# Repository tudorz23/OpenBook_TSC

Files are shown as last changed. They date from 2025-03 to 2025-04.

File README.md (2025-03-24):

*Designed by Marius-Tudor Zaharia, 333CA, March 2025*

# OpenBook

---

## What is OpenBook?
* OpenBook is an implementation of a performant, yet accessible e-book reader,
following an open-source philosophy, with Wi-Fi connectivity.
* It focuses on minimalism and offers a distraction-free body, with three
physical buttons for efficient navigation.
* It also promotes environmental awareness, encompassing temperature, humidity,
air pressure and air quality sensors.

---

## Block diagram
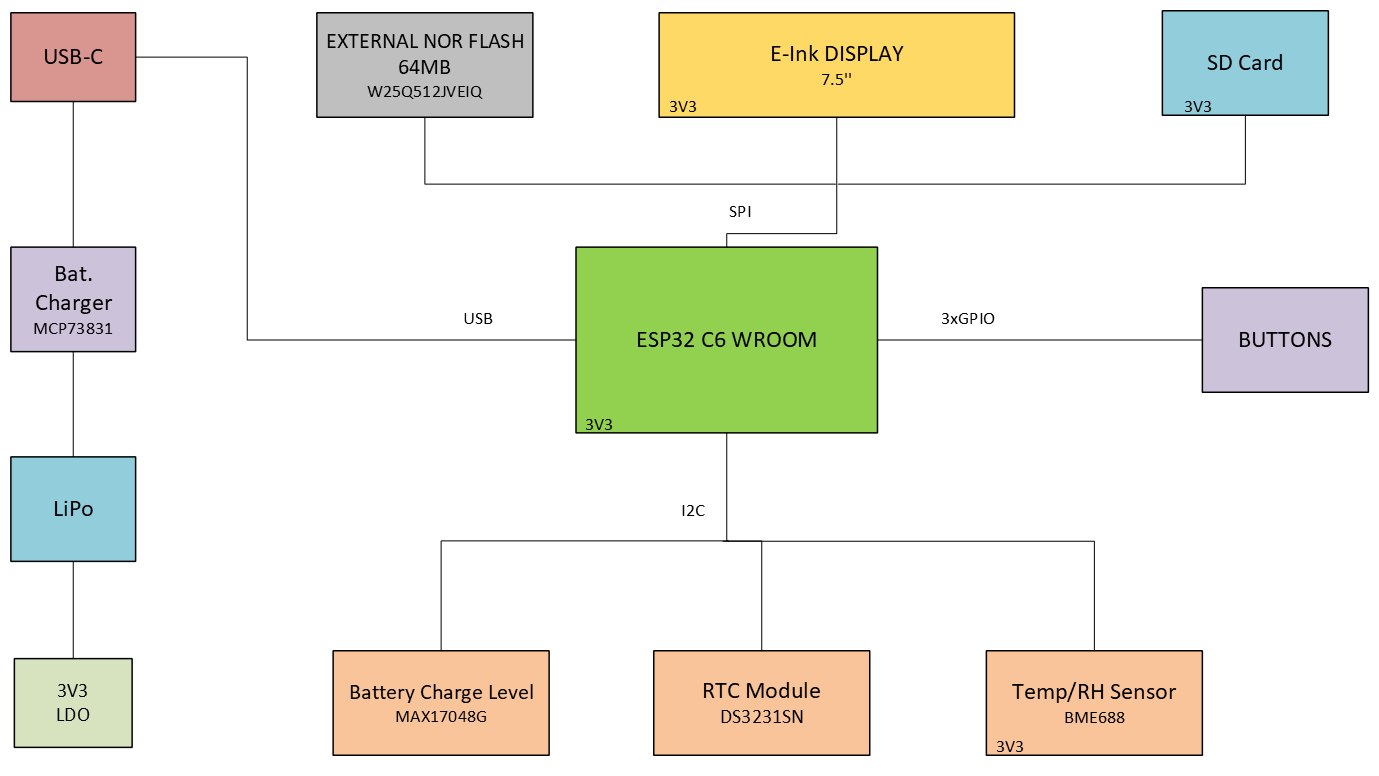
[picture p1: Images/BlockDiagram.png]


---

## Hardware description
### PCB
* The design of the PCB is centered around an **ESP32 C6 WROOM** microcontroller,
equipped with a 32-bit RISC-V single-core processor, up to 160MHz.
    * It offers 320 KB ROM, 512KB HP SRAM, 16KB LP SRAM.
    * It comes with Wi-Fi 6 and Bluetooth LE connectivity.
    * Supports GPIO, SPI, UART, I2C, LED PWM.

* The **ESP32** supports *5 power modes*, each with a different power consumption index:
    * *Active* - between 160 and 260mA
    * *Modem Sleep* - between 3 and 20mA
    * *Light Sleep* - 0.8mA
    * *Deep Sleep* - 10uA
    * *Hibernation* - 2.5uA

* **Three Buttons** are connected to 3 GPIO pins of the ESP32, allowing the user
                    to control the device:
    * *Reset* to **pin 3 - Enable**
    * *Boot* to **pin 15 - GPIO 9**
    * *Change* to **pin 23 - GPIO 15**

* **SD Card** socket, which communicates by SPI protocol:
    * *pin 2 - CD/DAT3* to **pin 4 - GPIO 4**
    * *pin 3 - CMD* to **pin 7** (MOSI, i.e. Serial Data Out, for SPI)
    * *pin 7 - DAT0* to **pin 27** (MISO, i.e. Serial Data In, for SPI)
    * *pin 5* to **pin 6 - clock**

* **E-Paper Display Header**, interfacing the external E-Ink Display, also by SPI.

* **External NOR Flash Memory 64MB**, by SPI too:
    * *pin 1 - CS* to **pin 12 - GPIO 11**
    * *pin 2* to **MOSI** (for SPI)
    * *pin 5* to **MISO** (for SPI)
    * *pin 6* to **pin 6 - clock**

* **RTC Module** - Real Time Clock, using I2C protocol:
    * *pin 4 - Reset* to **pin 16 - GPIO 18**
    * *pin 16 - SCL* to **pin 20 - GPIO 22** (for I2C)
    * *pin 15 - SDA* to **pin 19 - GPIO 21** (for I2C)
    * *pin 1* to **pin 9 - GPIO 1** (for 32KHz)
    * *pin 3 - SQW/INT* to **pin 8 - GPIO 0**
    * Has a battery backup input for continuous timekeeping.

* **BME688** - Digital low power pressure, temperature, humidity and gas sensor,
               also interfaced through I2C:
    * *pin 4 - SCK* to **pin 20 - GPIO 22** (SCL for I2C)
    * *pin 15 - SDI* to **pin 19 - GPIO 21** (SDA for I2C)
    * *pins 2, 6, 8* to **pin 17 - GPIO 19** (for I2C PW)
    * Power consumption is 3.7uA at 1Hz humidity, pressure and temperature scan
        and 0.15uA in sleep mode.

* **USB-C connector** - for fast, efficient charging.

* **Li-Po Battery Charging Controller** - MCP73831

* **LDO Voltage Regulator**

* **Battery Charge Level** - *MAX17048G+T10*, communicates by I2C interface:
    * *pin 7 - SCL* to **pin 20 - GPIO 22**
    * *pin 8 - SDA* to **pin 19 - GPIO 21**
    * Power consumption is 23uA in Active state and 3uA in Hibernate.

### External
* **7.5" E-Paper Display**
* **2500mAh Battery - LP584174**

---

## Bill Of Materials
| Component | Price (EUR) | Count | Provider | Datasheet |
| :--- | :--- | :---  | :--- | :--- |
| ESP32 C6| 2.99 | 1 | https://eu.mouser.com/ProductDetail/Espressif-Systems/ESP32-C6-WROOM-1U-N8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 | https://eu.mouser.com/datasheet/2/891/Espressif_Systems_7_11_2023_esp32_c6_wroom_1_wroom-3236277.pdf |
| USB-C connector| 0.39 | 1 | https://eu.mouser.com/ProductDetail/Same-Sky/UJC-H-G-SMT-2-P6-TR?qs=IKkN%2F947nfApFV8T6rOqww%3D%3D |https://eu.mouser.com/datasheet/2/1628/ujc_h_g_smt_2_p6_tr-3511211.pdf |
| USBLC6-2SC6Y | 0.44 | 1 | https://eu.mouser.com/ProductDetail/STMicroelectronics/USBLC6-2SC6Y?qs=gNDSiZmRJS%2FOgDexvXkdow%3D%3D | https://eu.mouser.com/datasheet/2/389/usblc6_2sc6y-1852505.pdf |
| PFMF.050.1 | 0.28 | 1 | https://eu.mouser.com/ProductDetail/Schurter/PFMF.050.2?qs=1auRipcfynCums5v1iucSA%3D%3D | https://eu.mouser.com/datasheet/2/358/typ_PFMF-1275918.pdf |
| DMG2305UX-7 | 0.19 | 2 | https://eu.mouser.com/ProductDetail/Diodes-Incorporated/DMG2305UX-7?qs=L1DZKBg7t5F%2FNBHrjfxC%252Bg%3D%3D | https://www.diodes.com/assets/Datasheets/DMG2305UX.pdf |
| SD0805S020S1R0 | 0.3 | 2 | https://eu.mouser.com/ProductDetail/KYOCERA-AVX/SD0805S020S1R0?qs=jCA%252BPfw4LHbpkAoSnwrdjw%3D%3D | https://eu.mouser.com/datasheet/2/40/schottky-3165252.pdf |
| XC6220A331MR-G | 1.46 | 1 | https://eu.mouser.com/ProductDetail/Torex-Semiconductor/XC6220A331MR-G?qs=AsjdqWjXhJ8ZSWznL1J0gg%3D%3D | https://eu.mouser.com/datasheet/2/760/xc6220-3371556.pdf |
| TANT Capacitor | 0.68 | 1 | https://eu.mouser.com/ProductDetail/Vishay-Sprague/293D107X9010D2TE3?qs=8dfOI6wKXonVqFgS8%252BQ%2FMA%3D%3D | https://www.vishay.com/docs/40002/293d.pdf |
| 112A-TAAR-R03 | 1.1 | 1 | https://store.comet.srl.ro/Catalogue/Product/43497/ | https://store.comet.bg/download-file.php?id=27596 |
| 68uH inductance | 0.9 | 1 | https://eu.mouser.com/ProductDetail/Vishay-Dale/IFDC5050JZER680M?qs=iLKYxzqNS745SePZd8tBoA%3D%3D | https://www.vishay.com/docs/34635/ifdc5050jz.pdf |
| MBR0530 | 0.14 | 3 | https://eu.mouser.com/ProductDetail/Micro-Commercial-Components-MCC/MBR0530-TP?qs=KFo7JewZbUECRHkxGanrdg%3D%3D | https://eu.mouser.com/datasheet/2/258/MBR0520_MBR0580_SOD123_-2492194.pdf |
| SI1308EDL-T1-GE3 | 0.42 | 2 | https://eu.mouser.com/ProductDetail/Vishay-Semiconductors/SI1308EDL-T1-GE3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 | https://www.vishay.com/docs/63399/si1308edl.pdf |
| Capacitor 0.1uF | 0.3 | 1 | https://eu.mouser.com/ProductDetail/KYOCERA-AVX/KGF21BR71H104KT?qs=Jm2GQyTW%2FbjYyKCvVWAEOw%3D%3D | https://eu.mouser.com/datasheet/2/40/KGF-3223650.pdf |
| Capacitor 1uF | 0.13 | 10 | https://eu.mouser.com/ProductDetail/TAIYO-YUDEN/MAASL105CC7105MFCA01?qs=HFfMDpzxxd1Fn%2FInbJA7vw%3D%3D | https://eu.mouser.com/datasheet/2/396/TAIYO_YUDEN_04_27_2024_c_mlcc_A_e1-3451516.pdf |
| Capacitor 4.7uF | 0.23 | 5 | https://eu.mouser.com/ProductDetail/KYOCERA-AVX/CM05X5R475M16AH?qs=doiCPypUmgFT1xquZKhWtQ%3D%3D | https://eu.mouser.com/datasheet/2/40/Kyocera_AVX_Components_CM025_CM05_CM105_CM21_E217K-2932876.pdf |
| Capacitor 10 uF | 0.47 | 1 | https://eu.mouser.com/ProductDetail/TDK/CGA3EDX7T1A106M080AU?qs=ZcfC38r4PovL%2FBNBUzzBFw%3D%3D | https://product.tdk.com/system/files/dam/doc/product/capacitor/ceramic/mlcc/catalog/mlcc_automotive_general_en.pdf |
| Capacitor 100nF | 0.3 | 8 | https://eu.mouser.com/ProductDetail/KYOCERA-AVX/KAM21BR71H104JT?qs=Jm2GQyTW%2Fbic6Zk4McEt6w%3D%3D | https://eu.mouser.com/datasheet/2/40/AutoMLCCKAM-3216307.pdf |
| Resistor 0.47 | 0.3 | 1 | https://eu.mouser.com/ProductDetail/SEI-Stackpole/RNCL1210FT50L0?qs=17ckDYBRdelVLOJ%252BDFjlUw%3D%3D | https://eu.mouser.com/datasheet/2/385/sei_rncl-3223524.pdf |
| Resistor 2.2 | 0.13 | 1 | https://eu.mouser.com/ProductDetail/YAGEO/RT1206FRE072R2L?qs=XhSZopxZ3H6S0nYZD83pAA%3D%3D | https://eu.mouser.com/datasheet/2/447/PYu_RT_1_to_0_01_RoHS_L_15-3461507.pdf |
| Resistor 15 | 0.25 | 1 | https://eu.mouser.com/ProductDetail/Panasonic/ERA-6AHD150V?qs=MNPzkKEzRtQip8ZeekU%252BRw%3D%3D | https://industrial.panasonic.com/cdbs/www-data/pdf/RDM0000/AOA0000C307.pdf |
Resistor 200 | 0.33 | 1 | https://eu.mouser.com/ProductDetail/TE-Connectivity-Holsworthy/RP73C2B200RFTDF?qs=n4i9pByFsMR0dWGpf721CA%3D%3D | https://eu.mouser.com/datasheet/2/418/10/ENG_DS_1773272_M1-1588495.pdf |
| Resistor 2k | 0.16 | 1 | https://eu.mouser.com/ProductDetail/Panasonic/ERA-3AED202V?qs=yocZuyCaXdM2cBmjcGkIyA%3D%3D | https://industrial.panasonic.com/cdbs/www-data/pdf/RDM0000/AOA0000C307.pdf |
| Resistor 5k1 | 0.15 | 2 | https://eu.mouser.com/ProductDetail/Vishay-Beyschlag/MCS04020C5101FE000?qs=wTZ%2FFzl837YsKPLPRIXUbg%3D%3D | https://www.vishay.com/docs/28705/mcx0x0xpro.pdf |
| Resistor 10k | 0.32 | 16 | https://eu.mouser.com/ProductDetail/SEI-Stackpole/RNWA0612BTE10K0?qs=IKkN%2F947nfD62pDKWE9ZTQ%3D%3D | https://eu.mouser.com/datasheet/2/385/SEI_RNWA-3473840.pdf |
| Resistor 100K | 0.1 | 1 | https://eu.mouser.com/ProductDetail/Panasonic/ERA-3AED104V?qs=MNPzkKEzRtQIWcmUWL4kjg%3D%3D | https://industrial.panasonic.com/cdbs/www-data/pdf/RDM0000/AOA0000C307.pdf |
| MCP73831 | 0.75 | 1 | https://eu.mouser.com/ProductDetail/Microchip-Technology/MCP73831-2ACI-MC?qs=hH%252BOa0VZEiBneYTVdpuVdg%3D%3D | https://eu.mouser.com/datasheet/2/268/MCP73831_Family_Data_Sheet_DS20001984H-3441711.pdf |
| FH34SRJ-24S-0.5SH(99) | 2.6 | 1 | https://eu.mouser.com/ProductDetail/Hirose-Connector/FH34SRJ-24S-0.5SH99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 | https://eu.mouser.com/datasheet/2/185/FH34SRJ_24S_0_5SH_99__CL0580_1255_6_99_2DDrawing_0-1615044.pdf |
| BME688 | 9.86 | 1 | https://eu.mouser.com/ProductDetail/Bosch-Sensortec/BME688?qs=IS%252B4QmGtzzqQoVDscqwx3A%3D%3D | https://eu.mouser.com/datasheet/2/783/bst_bme688_fl000-2307034.pdf |
| BD5229G-TR | 0.75 | 1 | https://eu.mouser.com/ProductDetail/ROHM-Semiconductor/BD5229G-TR?qs=4kLU8WoGk0vvnhrrYwdszw%3D%3D | https://fscdn.rohm.com/en/products/databook/datasheet/ic/power/voltage_detector/bd52xxg-e.pdf |
| MAX17048G+T10 | 4.28 | 1 | https://eu.mouser.com/ProductDetail/Analog-Devices-Maxim-Integrated/MAX17048G%2bT10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 | https://eu.mouser.com/datasheet/2/609/MAX17048_MAX17049-3469099.pdf |
| DS3231SN# | 14.91 | 1 | https://eu.mouser.com/ProductDetail/Analog-Devices-Maxim-Integrated/DS3231SN?qs=1eQvB6Dk1vhUlr8%2FOrV0Fw%3D%3D | https://eu.mouser.com/datasheet/2/609/DS3231-3421123.pdf |
| CPH3225A | 2.33 | 1 | https://eu.mouser.com/ProductDetail/Seiko-Semiconductors/CPH3225A?qs=3etwrb1wR%252BhUOph6lAO7eg%3D%3D | https://eu.mouser.com/datasheet/2/360/Seiko_Instruments_MicroBattery_E_20230330_2024Jan_-3561061.pdf |
| Qwiic | 3.75 | 1 | https://eu.mouser.com/ProductDetail/Adafruit/4208?qs=PzGy0jfpSMtbScLbr0L5dw%3D%3D | https://learn.adafruit.com/introducing-adafruit-stemma-qt/technical-specs |
| PGB1010603MR | 0.4 | 6 | https://eu.mouser.com/ProductDetail/Littelfuse/PGB1010603MR?qs=gu7KAQ731URLg4GSnNNN7Q%3D%3D | https://www.littelfuse.com/assetdocs/pulseguard-esd-suppressors-pgb1-datasheet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 |
| W25Q512JVEIQ | 5.84 | 1 | https://eu.mouser.com/ProductDetail/Winbond/W25Q512JVEIQ?qs=l7cgNqFNU1jw6svr3at6tA%3D%3D | https://eu.mouser.com/datasheet/2/949/Winbond_W25Q512JV_Datasheet-3240039.pdf |
| LP584174 Battery| 6.4 | 1 | https://www.tme.eu/en/details/accu-lp584174_cl/rechargeable-batteries/cellevia-batteries/l584174/ | https://www.tme.eu/Document/e0683d8c34e6d878124489f71bffb6ee/cel0014.pdf |
| E-Paper Display | 48 | 1 | https://eu.mouser.com/ProductDetail/Microtips-Technology/MT-DEPG0750BNU590F1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 | https://eu.mouser.com/datasheet/2/271/MT_DEPG0750BNU590F1_V2_7-1894282.pdf |

* **Total Cost** : 124.66 EUR

---

## Implementation steps
* Firstly, I drew the schematic, with all the components.
* I drew the shape of the PCB, then I placed the components, all of them on the
top plane, taking into account the position they will occupy in the external case.
* I drew the ground plane for both top and bottom, then I used the autorouter to
shape the routes. I manually routed those that were left as airwires and corrected
the ones that were not so greatly done.
* I set the power routes to a width of 0.3mm and solved all the issues from the
DRC check, such as the angles of the routes.
* After fine-tuning the silkscreen, I pushed the PCB to 3D and placed it into
the case, alongside the battery and the display.

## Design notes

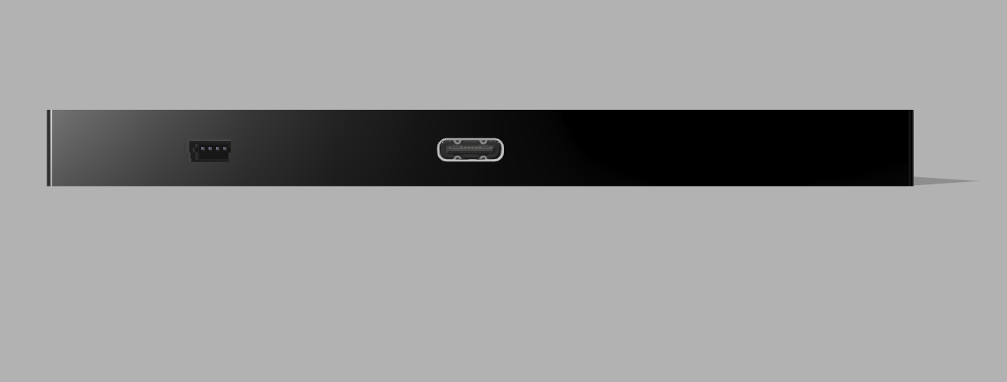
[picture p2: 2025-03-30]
Images/Device_bottom.png

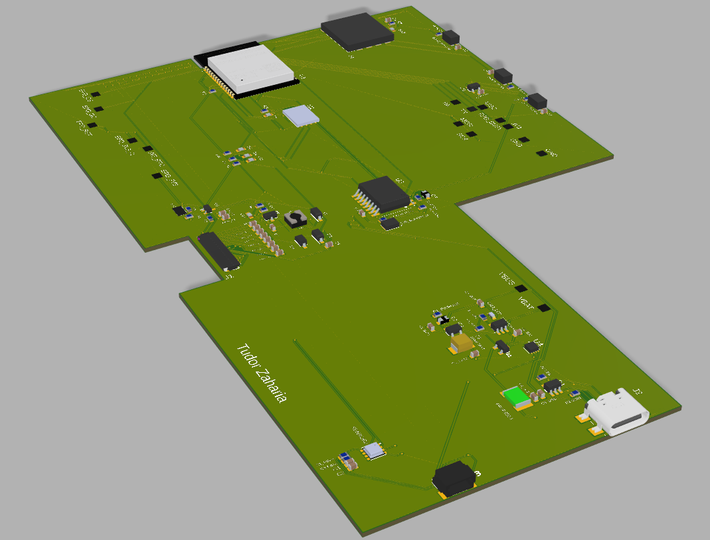
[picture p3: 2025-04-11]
Images/PCB_3D_side.png

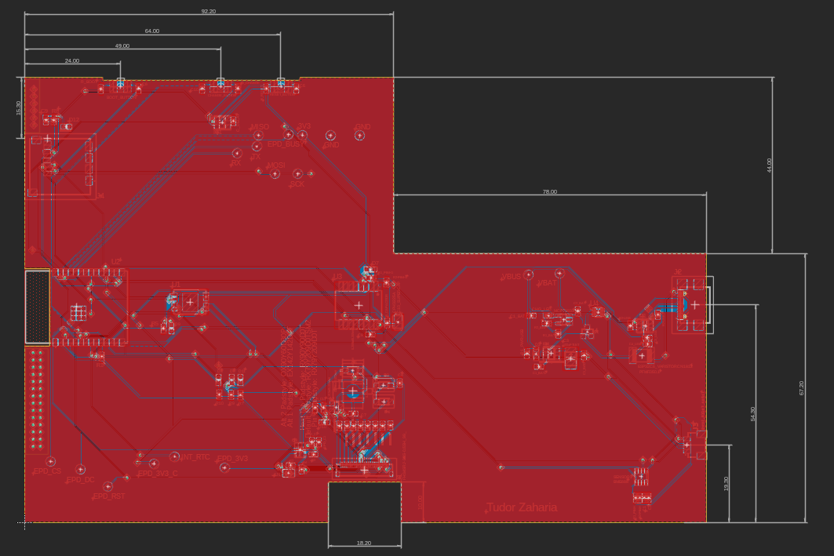
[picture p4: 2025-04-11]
Images/PCB_2D.png

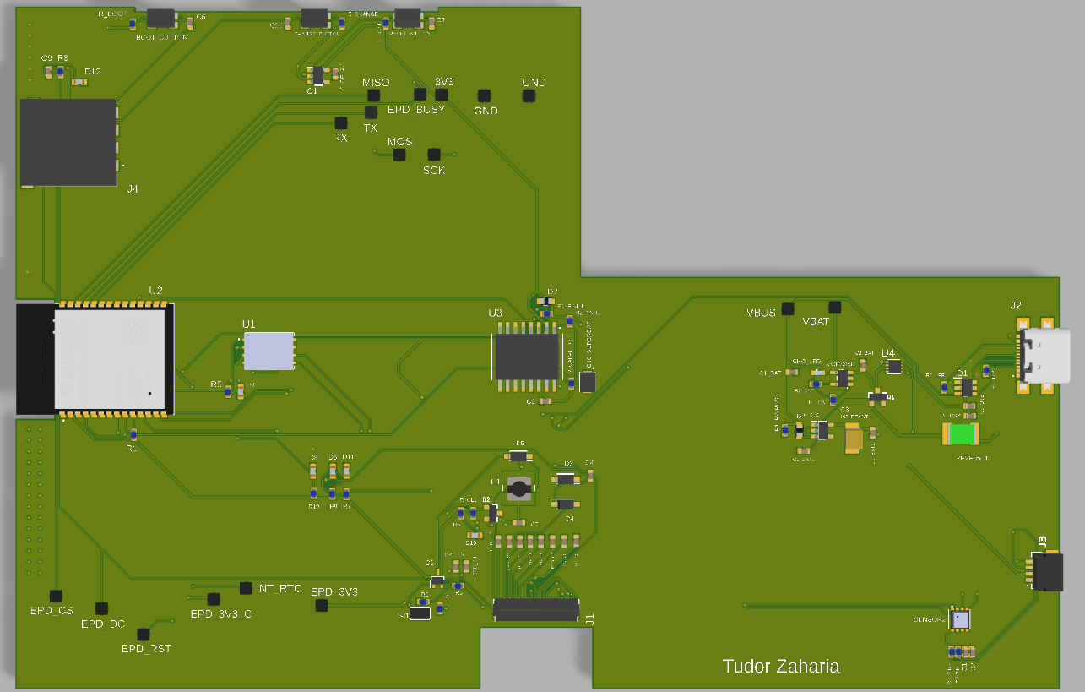
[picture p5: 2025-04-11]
Images/pcb_3d_top.png

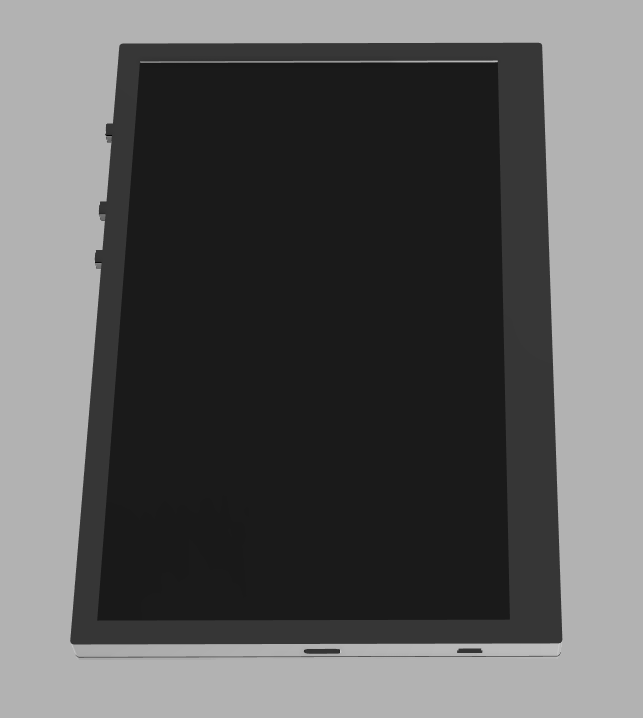
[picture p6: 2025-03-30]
Images/Device_display.png

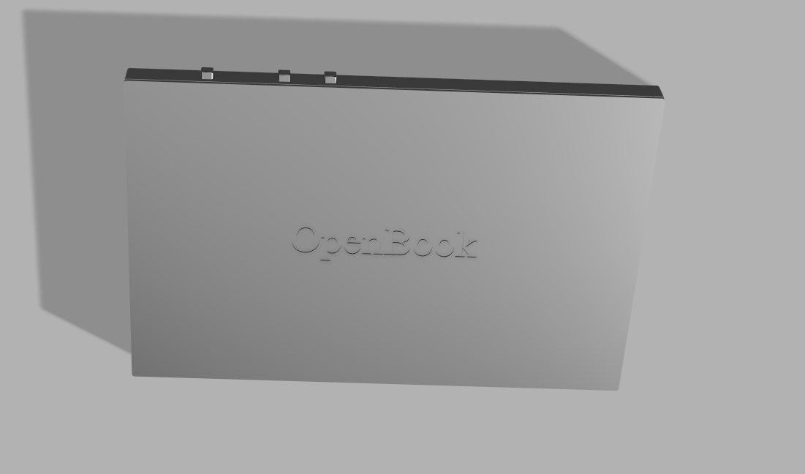
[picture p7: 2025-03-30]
Images/Device_back.png

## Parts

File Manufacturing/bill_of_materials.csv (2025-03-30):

Qty | Value | Device | Package | Parts | Description | ARROW_PART_NUMBER | ARROW_PRICE-STOCK | AVAILABILITY | CENTROID_NOT_SPECIFIED | CHECK_PRICES | COPYRIGHT | DATASHEET | DESCRIPTION | DIGIKEY_DESCRIPTION | DIGIKEY_PART_NUMBER | HEIGHT | LEAD_FREE | MANUFACTURER_NAME | MANUFACTURER_PART_NUMBER | MF | MFR_NAME | MOUSER_PART_NUMBER | MOUSER_PRICE-STOCK | MOUSER_TESTING_PART_NUMBER | MOUSER_TESTING_PRICE-STOCK | MP | MPN | PACKAGE | POPULARITY | PREFIX | PRICE | PROD_ID | PURCHASE-URL | ROHS | SNAPEDA_LINK | SPICEMODEL | SPICEPREFIX | TEMPERATURE_RANGE_HIGH | TEMPERATURE_RANGE_LOW | TP_SIGNAL_NAME | VALUE
1 |  | ADAFRUIT_LEDCHIP-LED0603 | ADAFRUIT_CHIP-LED0603 | CHG_LED | LED
1 |  | SJ | SJ | SJ1 | SMD solder JUMPER |  |  |  |  |  |  |  |  |  |  |  |  |  |  |  |  |  |  |  |  |  |  |  | 3
1 | 0.1uF/50V | EAGLE-LTSPICE_CC0402 | EAGLE-LTSPICE_C0402 | EPD_C5 | CAPACITOR, European symbol |  |  |  |  |  |  |  |  |  |  |  |  |  |  |  |  |  |  |  |  |  |  |  |  |  |  |  |  |  |  | NONE | C
1 | 0.47 | ESP32_WROVER_EAGLE-LTSPICE_RR0402 | ESP32_WROVER_EAGLE-LTSPICE_R0402 | R3 | RESISTOR, European symbol |  |  |  |  |  |  |  |  |  |  |  |  |  |  |  |  |  |  |  |  |  |  |  |  |  |  |  |  |  |  | NONE | R
1 | 100K | ESP32_WROVER_EAGLE-LTSPICE_RR0402 | ESP32_WROVER_EAGLE-LTSPICE_R0402 | R1_PWRUSB | RESISTOR, European symbol |  |  |  |  |  |  |  |  |  |  |  |  |  |  |  |  |  |  |  |  |  |  |  |  |  |  |  |  |  |  | NONE | R
8 | 100nF | EAGLE-LTSPICE_CC0402 | EAGLE-LTSPICE_C0402 | C1, C2, C4_USB, C6, C8, C9, C10, C_DELAY | CAPACITOR, European symbol |  |  |  |  |  |  |  |  |  |  |  |  |  |  |  |  |  |  |  |  |  |  |  |  |  |  |  |  |  |  | NONE | C
1 | 100uF TANT | RCL_CPOL-EUCT3528 | RCL_CT3528 | C3 | POLARIZED CAPACITOR, European symbol |  |  |  |  |  |  |  |  |  |  |  |  |  |  |  |  |  |  |  |  |  |  |  | 0 |  |  |  |  |  |  |  | C
16 | 10K | ESP32_WROVER_EAGLE-LTSPICE_RR0402 | ESP32_WROVER_EAGLE-LTSPICE_R0402 | R1, R1_PINH, R1_PINH1, R2-PINH, R2-PINH1, R4, R5, R6, R7, R8, R9, R10, R_BOOT, R_CHANGE, R_CL1, R_RESET | RESISTOR, European symbol |  |  |  |  |  |  |  |  |  |  |  |  |  |  |  |  |  |  |  |  |  |  |  |  |  |  |  |  |  |  | NONE | R
1 | 10uF | EAGLE-LTSPICE_CC0402 | EAGLE-LTSPICE_C0402 | C7 | CAPACITOR, European symbol |  |  |  |  |  |  |  |  |  |  |  |  |  |  |  |  |  |  |  |  |  |  |  |  |  |  |  |  |  |  | NONE | C
1 | 112A-TAAR-R03_ATTEND | 112A-TAAR-R03_ATTEND | 112ATAARR03ATTEND | J4 | Micro SD Card Socket, Push-Push Type, Top Mount, SMT, H=1.83mm, 10u |  |  |  |  |  |  |  | Micro SD Card Socket | Push-Push Type | Top Mount | SMT | H=1.83mm | 10u |  |  | 1.9mm |  | ATTEND | 112A-TAAR-R03 ATTEND
1 | 15 | ESP32_WROVER_EAGLE-LTSPICE_RR0402 | ESP32_WROVER_EAGLE-LTSPICE_R0402 | R_CAPACITOR | RESISTOR, European symbol |  |  |  |  |  |  |  |  |  |  |  |  |  |  |  |  |  |  |  |  |  |  |  |  |  |  |  |  |  |  | NONE | R
1 | 1uF | EAGLE-LTSPICE_CC0402 | EAGLE-LTSPICE_C0402 | C5 | CAPACITOR, European symbol |  |  |  |  |  |  |  |  |  |  |  |  |  |  |  |  |  |  |  |  |  |  |  |  |  |  |  |  |  |  | NONE | C
9 | 1uF/50V | EAGLE-LTSPICE_CC0402 | EAGLE-LTSPICE_C0402 | EPD_C1, EPD_C2, EPD_C6, EPD_C7, EPD_C8, EPD_C9, EPD_C10, EPD_C11, EPD_C12 | CAPACITOR, European symbol |  |  |  |  |  |  |  |  |  |  |  |  |  |  |  |  |  |  |  |  |  |  |  |  |  |  |  |  |  |  | NONE | C
1 | 2.2 | ESP32_WROVER_EAGLE-LTSPICE_RR0402 | ESP32_WROVER_EAGLE-LTSPICE_R0402 | R2 | RESISTOR, European symbol |  |  |  |  |  |  |  |  |  |  |  |  |  |  |  |  |  |  |  |  |  |  |  |  |  |  |  |  |  |  | NONE | R
1 | 200 | ESP32_WROVER_EAGLE-LTSPICE_RR0402 | ESP32_WROVER_EAGLE-LTSPICE_R0402 | R1_BAT | RESISTOR, European symbol |  |  |  |  |  |  |  |  |  |  |  |  |  |  |  |  |  |  |  |  |  |  |  |  |  |  |  |  |  |  | NONE | R
2 | 20V/4.2A/52mO/1.4W | ESP32_WROVER_SPARKFUN-DISCRETESEMI_MOSFET_PCH-DMG2305UX-7 | ESP32_WROVER_SPARKFUN-DISCRETESEMI_SOT23-3 | Q1, Q2 | P-channel MOSFETs |  |  |  |  |  |  |  |  |  |  |  |  |  |  |  |  |  |  |  |  |  |  |  |  |  |  | TRAN-14388 |  |  |  |  |  |  |  |  | 20V/4.2A/52mO/1.4W
1 | 2K | ESP32_WROVER_EAGLE-LTSPICE_RR0402 | ESP32_WROVER_EAGLE-LTSPICE_R0402 | R2_BAT | RESISTOR, European symbol |  |  |  |  |  |  |  |  |  |  |  |  |  |  |  |  |  |  |  |  |  |  |  |  |  |  |  |  |  |  | NONE | R
1 | 3V3 | TPTP20R | TP20R | TP16 | Test pad |  |  |  |  |  |  |  |  |  |  |  |  |  |  |  |  |  |  |  |  |  |  |  | 2
5 | 4.7uF | EAGLE-LTSPICE_CC0402 | EAGLE-LTSPICE_C0402 | C1_BAT, C1_BAT1, C1_BAT2, C2_BAT, C5_USB | CAPACITOR, European symbol |  |  |  |  |  |  |  |  |  |  |  |  |  |  |  |  |  |  |  |  |  |  |  |  |  |  |  |  |  |  | NONE | C
1 | 4.7uF/25V | EAGLE-LTSPICE_CC0402 | EAGLE-LTSPICE_C0402 | C4 | CAPACITOR, European symbol |  |  |  |  |  |  |  |  |  |  |  |  |  |  |  |  |  |  |  |  |  |  |  |  |  |  |  |  |  |  | NONE | C
2 | 5k1 | ESP32_WROVER_EAGLE-LTSPICE_RR0402 | ESP32_WROVER_EAGLE-LTSPICE_R0402 | R2-USB, R2-USB1 | RESISTOR, European symbol |  |  |  |  |  |  |  |  |  |  |  |  |  |  |  |  |  |  |  |  |  |  |  |  |  |  |  |  |  |  | NONE | R
1 | 68uH | 744043680IND_4828-WE-TPC_WRE | IND_4828-WE-TPC_WRE | L1 |  |  |  |  |  |  | Copyright (C) 2024 Ultra Librarian. All rights reserved. |  |  |  |  |  |  |  | 744043680 |  | Wurth Electronics
1 | BD5229G-TR | BD5229G-TR | SOT95P280X125-5N | IC1 | Voltage Detector with Adjustable Delay Time: CMOS processes are utilized to develop high precision, low current consumption CMOS reset ICs that allow arbitrary setting of the delay time. The extensive lineup includes both Nch Open Drain and CMOS output types in a wide range of detection voltages (from 2.3V to 6.0V, in 0.1V steps), enabling selection of the ideal solution based on customer requirements. In addition, the entire series is of course both lead-free and RoHS-compliant. |  |  |  |  |  |  |  | Voltage Detector with Adjustable Delay Time: CMOS processes are utilized to develop high precision | low current consumption CMOS reset ICs that allow arbitrary setting of the delay time. The extensive lineup includes both Nch Open Drain and CMOS output types in a wide range of detection voltages (from 2.3V to 6.0V | in 0.1V steps) | enabling selection of the ideal solution based on customer requirements. In addition | the entire series is of course both lead-free and RoHS-compliant. |  |  | 1.25mm |  | ROHM Semiconductor | BD5229G-TR |  |  | 755-BD5229G-TR | https://www.mouser.co.uk/ProductDetail/ROHM-Semiconductor/BD5229G-TR?qs=4kLU8WoGk0vvnhrrYwdszw%3D%3D
1 | BME688 | ESP32_WROVER_BME680_BME680 | ESP32_WROVER_BME680_PSON80P300X300X100-8N | SENSOR2 | Integrated Environmental Unit |  |  | Unavailable |  |  |  |  | Integrated Environmental Unit |  |  |  |  |  |  | Bosch Sensortec |  |  |  |  |  | BME680 |  | LGA-8 Bosch Tools |  |  | None
3 | BUTTON_CUSYOMV1 | BUTTON_CUSYOMV1 | MYBUTTON | BOOT_BUTTON, CHANGE_BUTTON, RESET_BUTTON
1 | CPH3225A | CPH3225A | CAPCP3225X100N | C10_SUPERCAP | Cap 0.011F 3.3V 1210 Flat Check availability |  |  | Not in stock |  | https://www.snapeda.com/parts/CPH3225A/Seiko+Instruments/view-part/?ref=eda |  |  | 11 mF (EDLC) Supercapacitor 3.3 V 1210 (3225 Metric) - - |  |  |  |  |  |  | Seiko Instruments |  |  |  |  |  | CPH3225A |  | 1210 Seiko |  |  | None |  | https://www.snapeda.com/api/url_track_click_mouser/?unipart_id=562593&manufacturer=Seiko Instruments&part_name=CPH3225A&search_term=None |  | https://www.snapeda.com/parts/CPH3225A/Seiko+Instruments/view-part/?ref=snap
1 | DS3231SN# | DS3231SN# | SOIC127P1032X265-16N | U3 | Real Time Clock Serial 16-Pin SOIC W T/R Check availability |  |  | In Stock |  | https://www.snapeda.com/parts/DS3231SN%23/Analog+Devices/view-part/?ref=eda |  |  | Extremely Accurate I²C-Integrated RTC/TCXO/Crystal |  |  |  |  |  |  | Analog Devices |  |  |  |  |  | DS3231SN# |  | SOIC-16 Maxim |  |  | None |  | https://www.snapeda.com/api/url_track_click_mouser/?unipart_id=99048&manufacturer=Analog Devices&part_name=DS3231SN#&search_term=None |  | https://www.snapeda.com/parts/DS3231SN%23/Analog+Devices/view-part/?ref=snap
1 | EPD_3V3 | TPTP20R | TP20R | TP17 | Test pad |  |  |  |  |  |  |  |  |  |  |  |  |  |  |  |  |  |  |  |  |  |  |  | 2
1 | EPD_3V3_C | TPTP20R | TP20R | TP13 | Test pad |  |  |  |  |  |  |  |  |  |  |  |  |  |  |  |  |  |  |  |  |  |  |  | 2
1 | EPD_BUSY | TPTP20R | TP20R | TP9 | Test pad |  |  |  |  |  |  |  |  |  |  |  |  |  |  |  |  |  |  |  |  |  |  |  | 2
1 | EPD_CS | TPTP20R | TP20R | TP10 | Test pad |  |  |  |  |  |  |  |  |  |  |  |  |  |  |  |  |  |  |  |  |  |  |  | 2
1 | EPD_DC | TPTP20R | TP20R | TP11 | Test pad |  |  |  |  |  |  |  |  |  |  |  |  |  |  |  |  |  |  |  |  |  |  |  | 2
1 | EPD_RST | TPTP20R | TP20R | TP12 | Test pad |  |  |  |  |  |  |  |  |  |  |  |  |  |  |  |  |  |  |  |  |  |  |  | 2
1 | ESP32-C6-WROOM-1-N8 | ESP32-C6-WROOM-1-N8 | XCVR_ESP32-C6-WROOM-1-N8 | U2 | Check availability |  |  | In Stock |  | https://www.snapeda.com/parts/ESP32-C6-WROOM-1-N8/Espressif+Systems/view-part/?ref=eda |  |  | Multiprotocol Modules ESP32-C6 module | Wi-Fi 6 in 2.4 GHz band | Bluetooth 5 | Zigbee 3.0 and Thread. ESP34-WROOM Compatible - ENGINEERING SAMPLE |  |  |  |  |  |  | Espressif Systems |  |  |  |  |  | ESP32-C6-WROOM-1-N8 |  | None |  |  | None |  |  |  | https://www.snapeda.com/parts/ESP32-C6-WROOM-1-N8/Espressif+Systems/view-part/?ref=snap
1 | ESP32C6_VARISTORCN1812 | ESP32C6_VARISTORCN1812 | ESP32C6_VARISTOR_CT/CN1812 | PFMF.050.1 | VARISTOR |  |  |  |  |  |  |  |  |  |  |  |  |  |  |  |  |  |  |  |  |  |  |  | 0
2 | ESP32_WROVER_AVX---SD0805S020S1R0_AVX_SD0805S020S1R0_0_0AVX_SD0805S020S1R0_0_0 | ESP32_WROVER_AVX---SD0805S020S1R0_AVX_SD0805S020S1R0_0_0AVX_SD0805S020S1R0_0_0 | ESP32_WROVER_AVX---SD0805S020S1R0_AVX_SD0805S020S1R0_0 | D2, D7 | Schottky Barrier Rectifier Diode |  |  |  | No |  |  | http://datasheets.avx.com/schottky.pdf |  | DIODE SCHOTTKY 20V 1A 0805 | 478-7800-1-ND |  | yes |  |  | AVX |  | 581-SD0805S020S1R0 |  |  |  |  |  | 0805 (2012 metric) |  | D |  |  |  | yes |  |  |  | +125°C | -55°C
1 | ESP32_WROVER_SPARKFUN-IC-POWER_MCP73831 | ESP32_WROVER_SPARKFUN-IC-POWER_MCP73831 | ESP32_WROVER_SPARKFUN-IC-POWER_SOT23-5 | MCP73831 | MCP73831T Li-Ion, Li-Pol Controller |  |  |  |  |  |  |  |  |  |  |  |  |  |  |  |  |  |  |  |  |  |  |  |  |  |  | IC-09995
1 | FH34SRJ-24S-0.5SH_99_ | FH34SRJ-24S-0.5SH_99_ | FH34SRJ24S05SH99 | J1 | (0.50mm) Surface Mount, Right Angle |  |  |  |  |  |  |  | 24 Position FFC | FPC Connector Contacts | (0.50mm) Surface Mount | Right Angle |  |  | 1.1mm |  | Hirose | FH34SRJ-24S-0.5SH(99) |  |  | 798-FH34SRJ24S05SH99 | https://www.mouser.co.uk/ProductDetail/Hirose-Connector/FH34SRJ-24S-0.5SH99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
2 | GND | TPTP20R | TP20R | TP4, TP5 | Test pad |  |  |  |  |  |  |  |  |  |  |  |  |  |  |  |  |  |  |  |  |  |  |  | 2
1 | INT_RTC | TPTP20R | TP20R | TP15 | Test pad |  |  |  |  |  |  |  |  |  |  |  |  |  |  |  |  |  |  |  |  |  |  |  | 2
1 | MAX17048G+T10 | MAX17048G+T10 | SON50P200X200X80-9N | U4 | Check availability |  |  | In Stock |  | https://www.snapeda.com/parts/MAX17048G+T10/Analog+Devices/view-part/?ref=eda |  |  | 3µA 1-Cell/2-Cell Fuel Gauge with ModelGauge |  |  |  |  |  |  | Analog Devices |  |  |  |  |  | MAX17048G+T10 |  | TDFN-8 Maxim |  |  | None |  | https://www.snapeda.com/api/url_track_click_mouser/?unipart_id=329239&manufacturer=Analog Devices&part_name=MAX17048G+T10&search_term=None |  | https://www.snapeda.com/parts/MAX17048G+T10/Analog+Devices/view-part/?ref=snap
3 | MBR0530 | MBR0530 | SOD3716X135N | D3, D4, D5 | ON SEMICONDUCTOR - MBR0530 - DIODE, SCHOTTKY, 0.5A, 30V, SOD-123 |  |  | In Stock |  | https://www.snapeda.com/parts/MBR0530/Onsemi/view-part/?ref=eda |  |  | Diode Schottky 30 V 500mA Surface Mount SOD-123 |  |  |  |  |  |  | ON Semiconductor |  |  |  |  |  | MBR0530 |  | SOD-123-2 ON Semiconductor |  |  | None |  | https://www.snapeda.com/api/url_track_click_mouser/?unipart_id=179458&manufacturer=ON Semiconductor&part_name=MBR0530&search_term=None |  | https://www.snapeda.com/parts/MBR0530/Onsemi/view-part/?ref=snap
1 | MISO | TPTP20R | TP20R | TP6 | Test pad |  |  |  |  |  |  |  |  |  |  |  |  |  |  |  |  |  |  |  |  |  |  |  | 2
1 | MOSI | TPTP20R | TP20R | TP7 | Test pad |  |  |  |  |  |  |  |  |  |  |  |  |  |  |  |  |  |  |  |  |  |  |  | 2
6 | PGB1010603MR | PGB1010603MR | DIOC1608X36N | D6, D8, D9, D10, D11, D12 | Check availability |  |  | In Stock |  | https://www.snapeda.com/parts/PGB1010603MR/Littelfuse/view-part/?ref=eda |  |  | 150V (Typ) Clamp - Ipp Tvs Diode Surface Mount 0603 (1608 Metric) |  |  |  |  |  |  | Littelfuse Inc. |  |  |  |  |  | PGB1010603MR |  | 0603 Littelfuse Inc. |  |  | None |  | https://www.snapeda.com/api/url_track_click_mouser/?unipart_id=5659453&manufacturer=Littelfuse Inc.&part_name=PGB1010603MR&search_term=None |  | https://www.snapeda.com/parts/PGB1010603MR/Littelfuse/view-part/?ref=snap
1 | QWIIC_RIGHT_ANGLE | QWIIC_CONNECTORJS-1MM | JST04_1MM_RA | J3 | SparkFun I2C Standard Qwiic Connector |  |  |  |  |  |  |  |  |  |  |  |  |  |  |  |  |  |  |  |  |  |  |  |  |  |  | CONN-13694 |  |  |  |  |  |  |  |  | QWIIC_RIGHT_ANGLE
1 | RX | TPTP20R | TP20R | TP2 | Test pad |  |  |  |  |  |  |  |  |  |  |  |  |  |  |  |  |  |  |  |  |  |  |  | 2
1 | SAMACSYS_PARTS_USB4110-GF-A | SAMACSYS_PARTS_USB4110-GF-A | SAMACSYS_PARTS_USB4110GFA | J2 | CONN USB 2.0 TYPE-C R/A SMT |  |  |  |  |  |  |  | CONN USB 2.0 TYPE-C R/A SMT |  |  | 3.26mm |  | GCT (GLOBAL CONNECTOR TECHNOLOGY) | USB4110-GF-A |  |  | 640-USB4110-GF-A | https://www.mouser.co.uk/ProductDetail/GCT/USB4110-GF-A?qs=KUoIvG%2F9IlYiZvIXQjyJeA%3D%3D
1 | SCK | TPTP20R | TP20R | TP8 | Test pad |  |  |  |  |  |  |  |  |  |  |  |  |  |  |  |  |  |  |  |  |  |  |  | 2
1 | SI1308EDL-T1-GE3 | SI1308EDL-T1-GE3 | SOT65P210X110-3N | Q3 | MOSFET N-Ch 30V 1.5A TrenchFET SC70 Vishay Si1308EDL-T1-GE3 N-channel MOSFET Transistor, 1.5 A, 30 V, 3-Pin SC-70 |  |  | In Stock |  | https://www.snapeda.com/parts/SI1308EDL-T1-GE3/Vishay+Siliconix/view-part/?ref=eda |  |  | Si1308EDL-T1-GE3 N-channel MOSFET Transistor | 1.5 A | 30 V | 3-Pin SC-70 | Siliconix / Vishay SI1308EDL-T1-GE3 |  |  |  |  |  |  | Vishay Siliconix |  |  |  |  |  | SI1308EDL-T1-GE3 |  | SOT-323 Vishay Semiconductor |  |  | None |  | https://www.snapeda.com/api/url_track_click_mouser/?unipart_id=274603&manufacturer=Vishay Siliconix&part_name=SI1308EDL-T1-GE3&search_term=None |  | https://www.snapeda.com/parts/SI1308EDL-T1-GE3/Vishay+Siliconix/view-part/?ref=snap
1 | TX | TPTP20R | TP20R | TP1 | Test pad |  |  |  |  |  |  |  |  |  |  |  |  |  |  |  |  |  |  |  |  |  |  |  | 2
1 | USBLC6-2SC6Y | USBLC6-2SC6Y | SOT95P280X145-6N | D1 | Low Cap. ESD Protection Auto SOT-23-6 STMicroelectronics USBLC6-2SC6Y, Dual Uni-Directional TVS Diode Array, 6-Pin SOT-23 |  |  | In Stock |  | https://www.snapeda.com/parts/USBLC6-2SC6Y/STMicroelectronics/view-part/?ref=eda |  |  | 17V Clamp 5A (8/20µs) Ipp Tvs Diode Surface Mount SOT-23-6 |  |  |  |  |  |  | STMicroelectronics |  |  |  |  |  | USBLC6-2SC6Y |  | SOT-23-6 STMicroelectronics |  |  | None |  |  |  | https://www.snapeda.com/parts/USBLC6-2SC6Y/STMicroelectronics/view-part/?ref=snap
1 | VBAT | TPTP20R | TP20R | TP3 | Test pad |  |  |  |  |  |  |  |  |  |  |  |  |  |  |  |  |  |  |  |  |  |  |  | 2
1 | VBUS | TPTP20R | TP20R | TP14 | Test pad |  |  |  |  |  |  |  |  |  |  |  |  |  |  |  |  |  |  |  |  |  |  |  | 2
1 | W25Q512JVEIQ | W25Q512JVEIQ | SON127P600X800X80-9N | U1 | Check availability |  |  | In Stock |  | https://www.snapeda.com/parts/W25Q512JVEIQ/Winbond+Electronics/view-part/?ref=eda |  |  | FLASH - NOR Memory IC 512Mb (64M x 8) SPI - Quad I/O 133 MHz 8-WSON (8x6) |  |  |  |  |  |  | Winbond Electronics |  |  |  |  |  | W25Q512JVEIQ |  | Package |  |  | None |  |  |  | https://www.snapeda.com/parts/W25Q512JVEIQ/Winbond+Electronics/view-part/?ref=snap
1 | XC6220A331MR-G | XC6220A331MR-G | SOT95P280X120-5N | IC4 | LDO Voltage Regulators |  |  |  |  |  |  |  | LDO Voltage Regulators |  |  | 1.2mm |  | Torex | XC6220A331MR-G |  |  | 865-XC6220A331MR-G | https://www.mouser.co.uk/ProductDetail/Torex-Semiconductor/XC6220A331MR-G?qs=AsjdqWjXhJ8ZSWznL1J0gg%3D%3D

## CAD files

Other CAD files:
Mechanical/OpenBook_device_fusion.f3z

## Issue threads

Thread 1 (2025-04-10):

[Schematic] Nume lipsă

paularusen, 2025-04-10:
Pentru componentele Q2(EPD Power), D2(LDO Voltage Regulator) și D7(RTC Module DS3231SN) lipsesc numele componentelor fizice, care sunt notate în schematicul model.

tudorz23, 2025-04-11:
Done!

Closed 2025-04-11.

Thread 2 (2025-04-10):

[PCB] Via Stitching

paularusen, 2025-04-10:
Lipsește Via Stitching între cele două planuri de masă sau este o eroare produsă de program?

tudorz23, 2025-04-11:
Via Stitching-ul este pus in preajma lui ESP32. Intr-adevar, din ce am citit, nu se exporta bine Via Stitching in format ".brd". Am remarcat si eu acest aspect cand am facut review, deci banuiesc ca este in regula.

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

Closed 2025-04-11.

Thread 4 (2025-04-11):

[PCB 3D] Pozitionare display

paularusen, 2025-04-11:
În modelul 3D al device-ului, ecranul și PCB-ul pare că se suprapun. Cred că ar ajuta să muți ecranul spre exteriorul carcasei.
O să îți atașez o poză, astfel încât să poți observa problema identificată.

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

tudorz23, 2025-04-11:
Rezolvat, multumesc!

Closed 2025-04-11.

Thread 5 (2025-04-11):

[PCB 2D] Unghiuri drepte

paularusen, 2025-04-11:
Toate traseele arată foarte bine, dar există 2 mici omisiuni:

1. Între Q2 si R_CL1:

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

2.  În partea dreaptă a plăcii, între C1_BAT2 și varistor, lângă via-ul de jos:

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

tudorz23, 2025-04-11:
Done!

Closed 2025-04-11.

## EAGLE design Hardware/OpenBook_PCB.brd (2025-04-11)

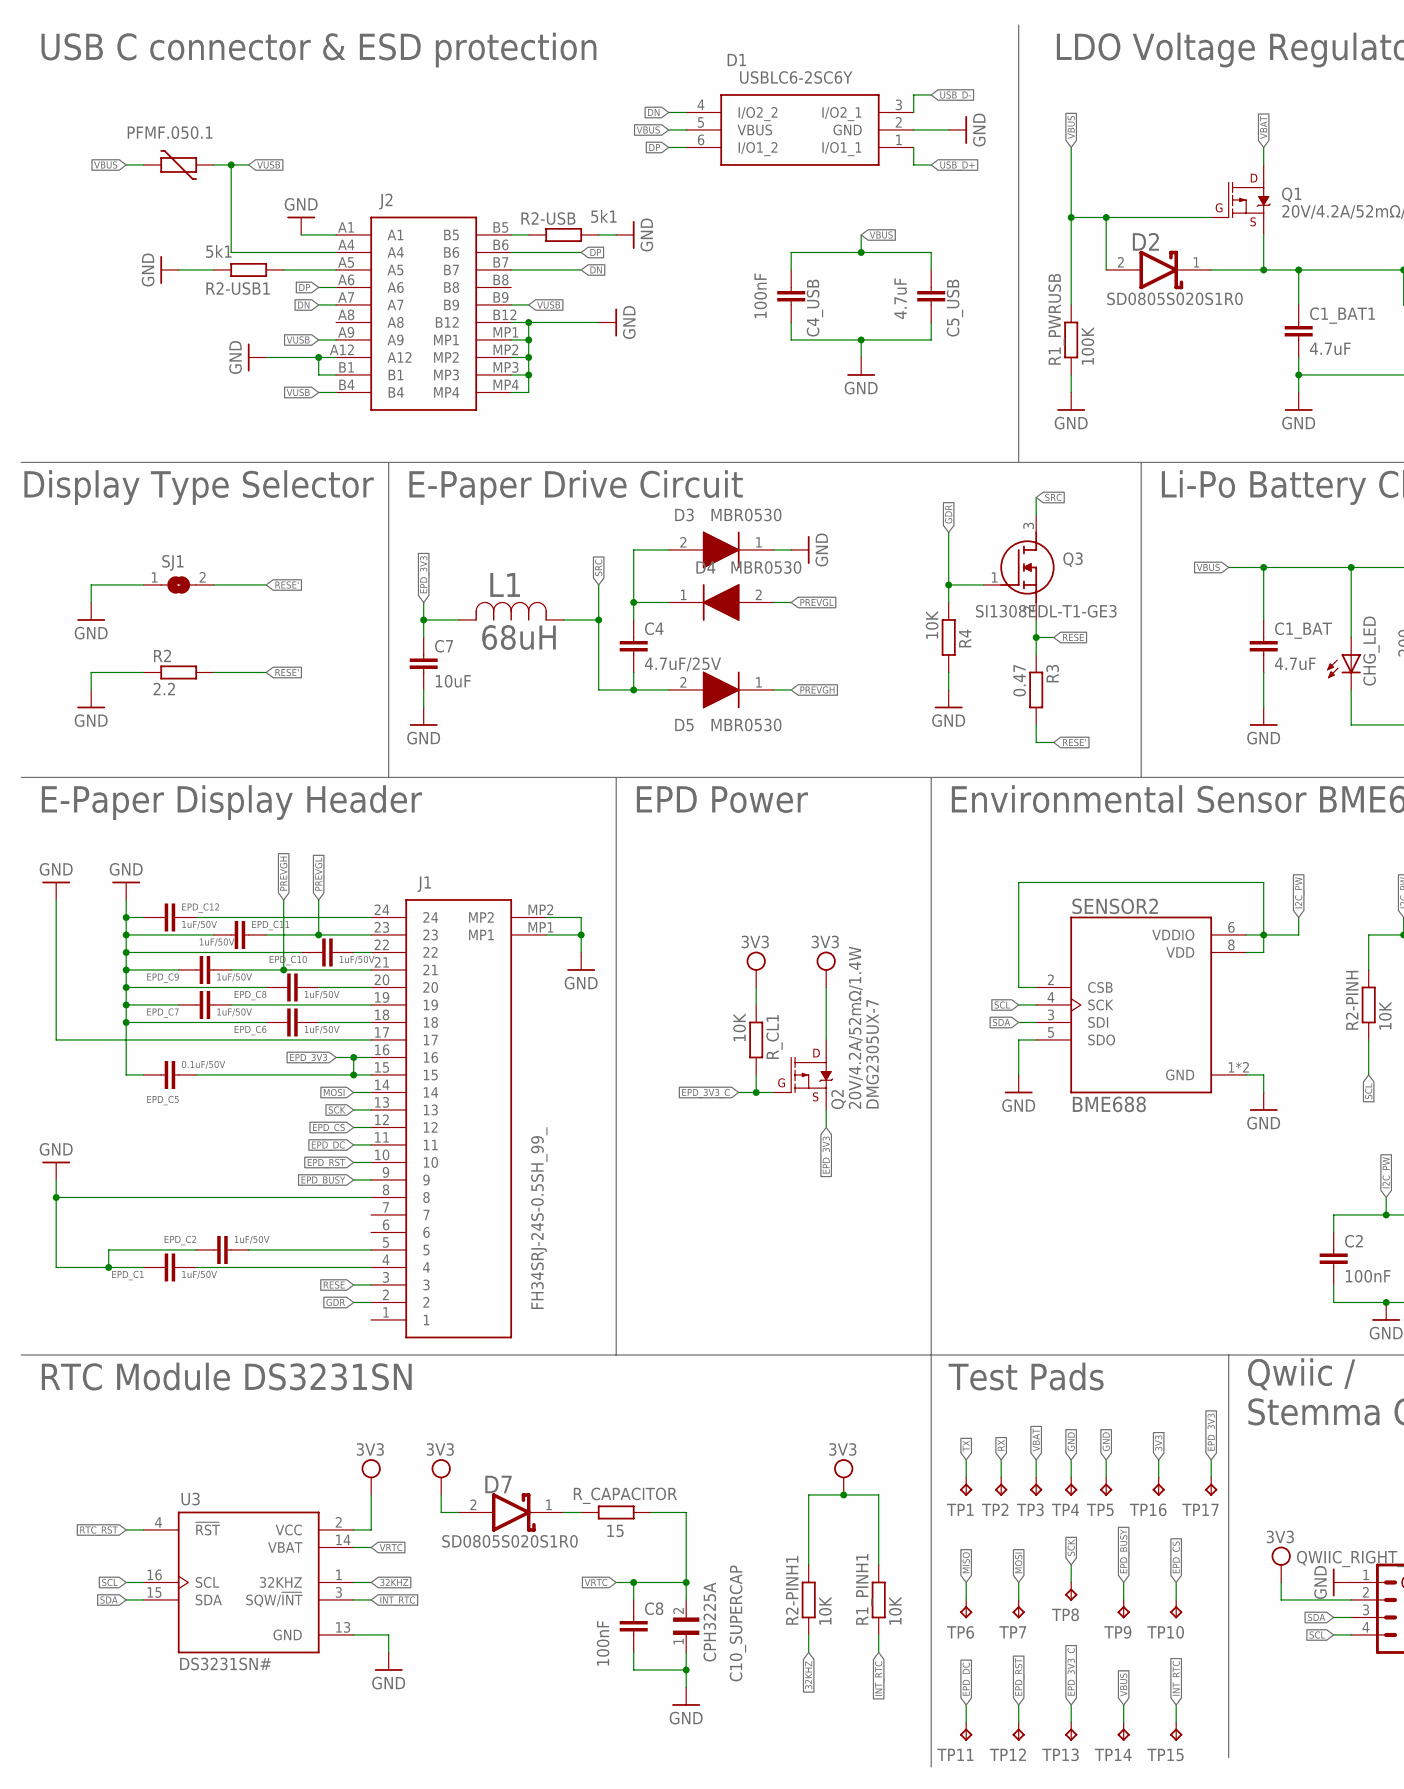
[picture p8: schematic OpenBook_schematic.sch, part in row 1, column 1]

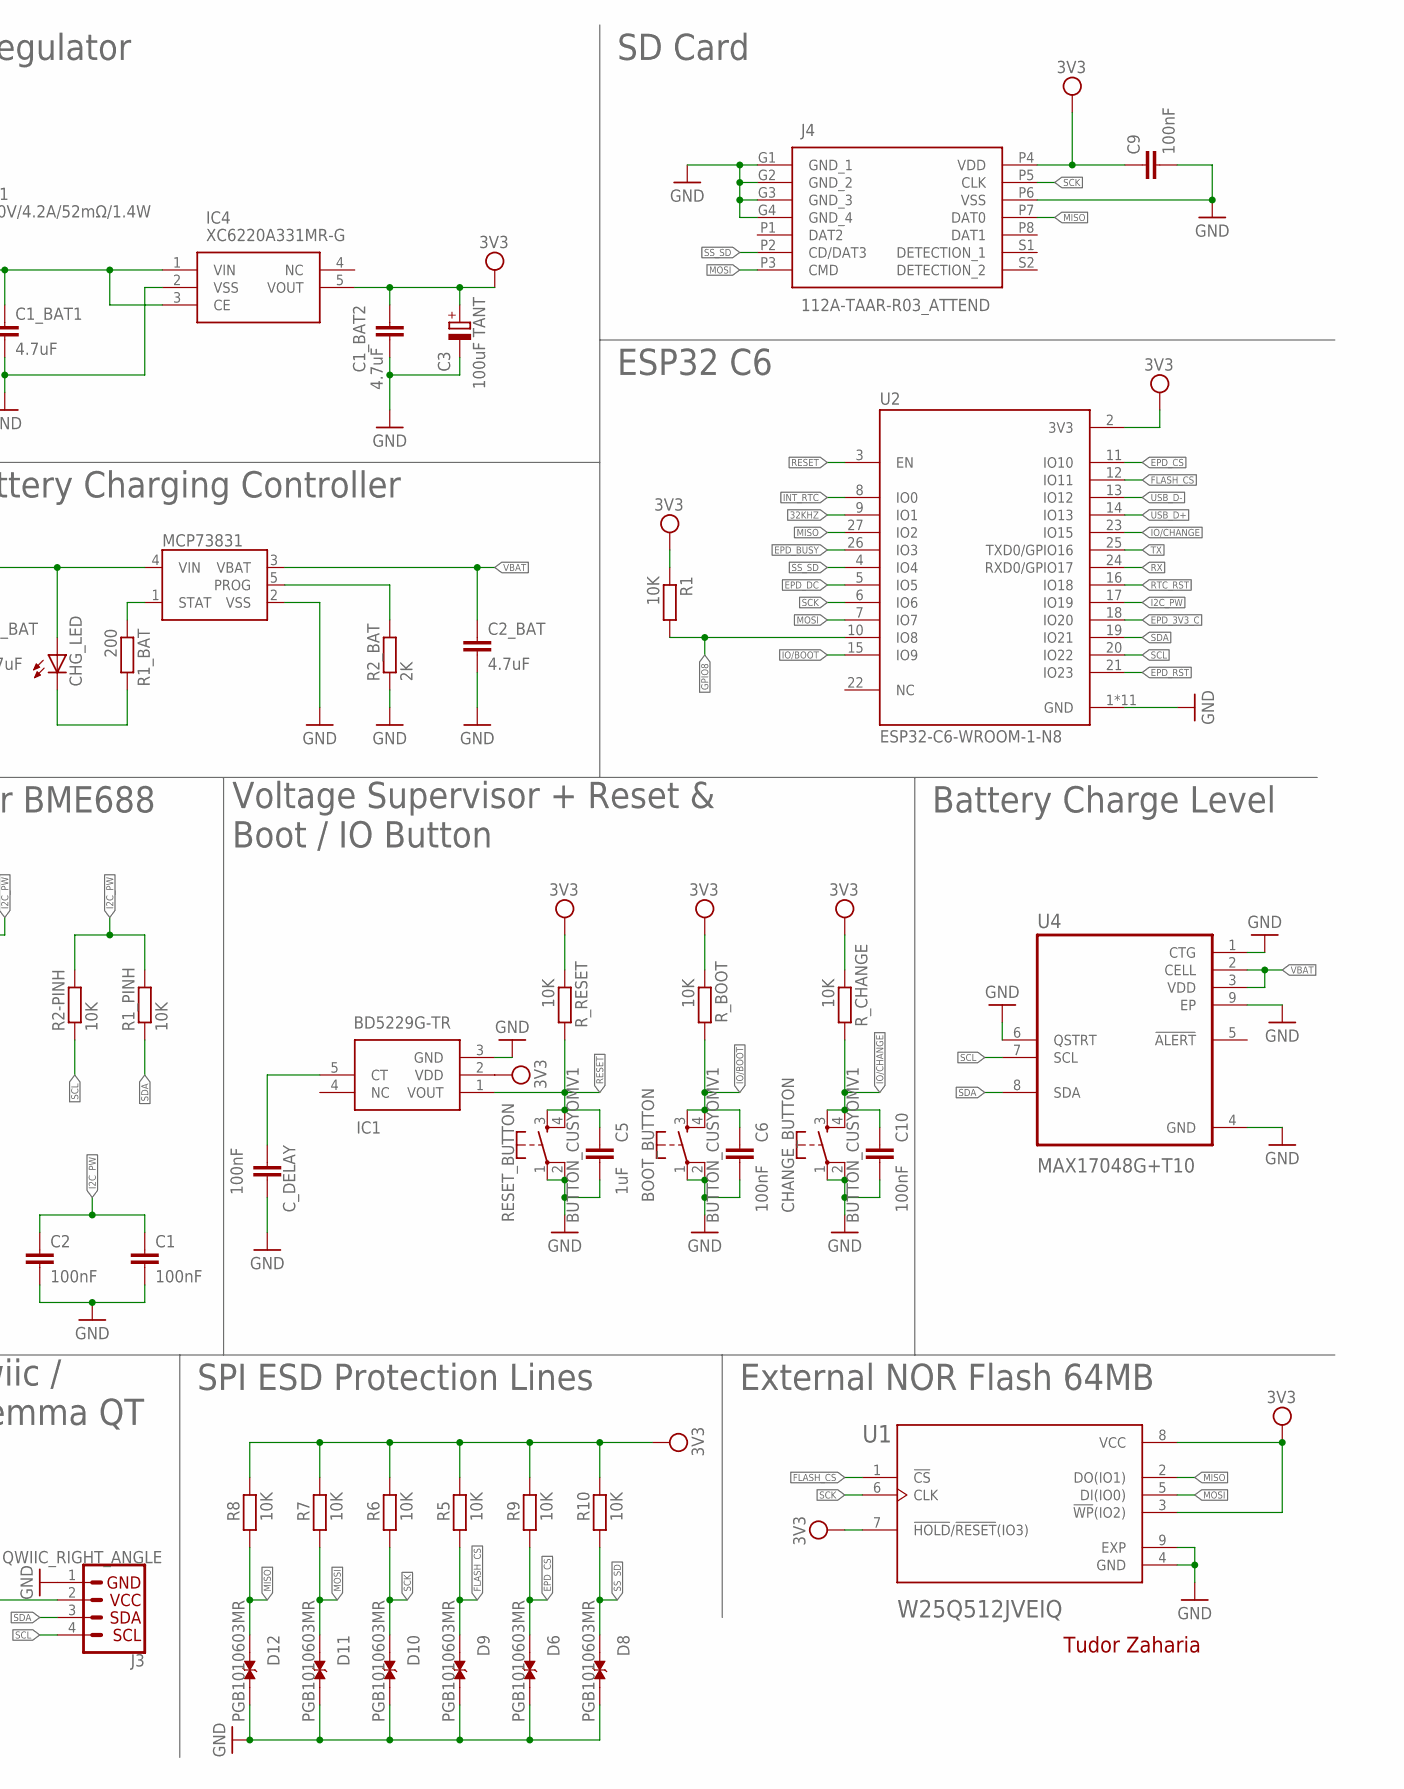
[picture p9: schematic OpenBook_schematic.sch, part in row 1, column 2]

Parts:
BOOT_BUTTON: BUTTON_CUSYOMV1; MYBUTTON
C1, C2, C4_USB, C6, C8, C9, C10: 100nF; EAGLE-LTSPICE_C0402
C1_BAT, C1_BAT1, C1_BAT2, C2_BAT, C5_USB: 4.7uF; EAGLE-LTSPICE_C0402
C3: 100uF TANT; RCL_CT3528
C4: 4.7uF/25V; EAGLE-LTSPICE_C0402
C5: 1uF; EAGLE-LTSPICE_C0402
C7: 10uF; EAGLE-LTSPICE_C0402
C10_SUPERCAP: CPH3225A; CAPCP3225X100N
CHANGE_BUTTON: BUTTON_CUSYOMV1; MYBUTTON
CHG_LED: ADAFRUIT_LEDCHIP-LED0603; ADAFRUIT_CHIP-LED0603
C_DELAY: 100nF; EAGLE-LTSPICE_C0402
D1: USBLC6-2SC6Y; SOT95P280X145-6N
D2, D7: ESP32_WROVER_AVX---SD0805S020S1R0_AVX_SD0805S020S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; ESP32_WROVER_AVX---SD0805S020S1R0_AVX_SD0805S020S1R0_0
D3, D4, D5: MBR0530; SOD3716X135N
D6, D8, D9, D10, D11, D12: PGB1010603MR; DIOC1608X36N
EPD_C1, EPD_C2, EPD_C6, EPD_C7, EPD_C8, EPD_C9, EPD_C10, EPD_C11, EPD_C12: 1uF/50V; EAGLE-LTSPICE_C0402
EPD_C5: 0.1uF/50V; EAGLE-LTSPICE_C0402
IC1: BD5229G-TR; SOT95P280X125-5N
IC4: XC6220A331MR-G; SOT95P280X120-5N
J1: FH34SRJ-24S-0.5SH_99_; FH34SRJ24S05SH99
J2: SAMACSYS_PARTS_USB4110-GF-A; SAMACSYS_PARTS_USB4110GFA
J3: QWIIC_RIGHT_ANGLE; JST04_1MM_RA
J4: 112A-TAAR-R03_ATTEND; 112ATAARR03ATTEND
L1: 68uH; IND_4828-WE-TPC_WRE
MCP73831: ESP32_WROVER_SPARKFUN-IC-POWER_MCP73831; ESP32_WROVER_SPARKFUN-IC-POWER_SOT23-5
PFMF.050.1: ESP32C6_VARISTORCN1812; ESP32C6_VARISTOR_CT/CN1812
Q1, Q2: 20V/4.2A/52mΩ/1.4W; ESP32_WROVER_SPARKFUN-DISCRETESEMI_SOT23-3
Q3: SI1308EDL-T1-GE3; SOT65P210X110-3N
R1, R1_PINH, R1_PINH1, R2-PINH, R2-PINH1, R4, R5, R6, R7, R8, R9, R10: 10K; ESP32_WROVER_EAGLE-LTSPICE_R0402
R1_BAT: 200; ESP32_WROVER_EAGLE-LTSPICE_R0402
R1_PWRUSB: 100K; ESP32_WROVER_EAGLE-LTSPICE_R0402
R2: 2.2; ESP32_WROVER_EAGLE-LTSPICE_R0402
R2-USB, R2-USB1: 5k1; ESP32_WROVER_EAGLE-LTSPICE_R0402
R2_BAT: 2K; ESP32_WROVER_EAGLE-LTSPICE_R0402
R3: 0.47; ESP32_WROVER_EAGLE-LTSPICE_R0402
RESET_BUTTON: BUTTON_CUSYOMV1; MYBUTTON
R_BOOT: 10K; ESP32_WROVER_EAGLE-LTSPICE_R0402
R_CAPACITOR: 15; ESP32_WROVER_EAGLE-LTSPICE_R0402
R_CHANGE: 10K; ESP32_WROVER_EAGLE-LTSPICE_R0402
R_CL1: 10K; ESP32_WROVER_EAGLE-LTSPICE_R0402
R_RESET: 10K; ESP32_WROVER_EAGLE-LTSPICE_R0402
SENSOR2: BME688; ESP32_WROVER_BME680_PSON80P300X300X100-8N
SJ1: SJ
TP1: TX; TP20R
TP2: RX; TP20R
TP3: VBAT; TP20R
TP4, TP5: GND; TP20R
TP6: MISO; TP20R
TP7: MOSI; TP20R
TP8: SCK; TP20R
TP9: EPD_BUSY; TP20R
TP10: EPD_CS; TP20R
TP11: EPD_DC; TP20R
TP12: EPD_RST; TP20R
TP13: EPD_3V3_C; TP20R
TP14: VBUS; TP20R
TP15: INT_RTC; TP20R
TP16: 3V3; TP20R
TP17: EPD_3V3; TP20R
U1: W25Q512JVEIQ; SON127P600X800X80-9N
U2: ESP32-C6-WROOM-1-N8; XCVR_ESP32-C6-WROOM-1-N8
U3: DS3231SN#; SOIC127P1032X265-16N
U4: MAX17048G+T10; SON50P200X200X80-9N

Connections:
3V3: C1_BAT2.1, C3.+, C9.1, D7.2 (ANODE), IC1.2 (VDD), IC4.5 (VOUT), J3.2, J4.P4 (VDD), Q2.3 (D), R1.1, R1_PINH1.2, R2-PINH1.2, R5.2, R6.2, R7.2, R8.2, R9.2, R10.2, R_BOOT.1, R_CHANGE.1, R_CL1.1, R_RESET.1, TP16.TP, U1.3 (!WP!(IO2)), U1.7 (!HOLD!/!RESET!(IO3)), U1.8 (VCC), U2.2 (3V3), U3.2 (VCC)
32KHZ: R2-PINH1.1, U2.9 (IO1), U3.1 (32KHZ)
DN: D1.4 (I/O2_2), J2.A7, J2.B7
DP: D1.6 (I/O1_2), J2.A6, J2.B6
EPD_3V3: C7.1, EPD_C5.1, J1.15, J1.16, L1.2, Q2.2 (S), TP17.TP
EPD_3V3_C: Q2.1 (G), R_CL1.2, TP13.TP, U2.18 (IO20)
EPD_BUSY: J1.9, TP9.TP, U2.26 (IO3)
EPD_CS: D6.1, J1.12, R9.1, TP10.TP, U2.11 (IO10)
EPD_DC: J1.11, TP11.TP, U2.5 (IO5)
EPD_RST: J1.10, TP12.TP, U2.21 (IO23)
FLASH_CS: D9.1, R5.1, U1.1 (!CS), U2.12 (IO11)
GDR: J1.2, Q3.1 (G), R4.1
GND: BOOT_BUTTON.1, BOOT_BUTTON.2, C1.2, C1_BAT.2, C1_BAT1.2, C1_BAT2.2, C2.2, C2_BAT.2, C3.-, C4_USB.2, C5.2, C5_USB.2, C6.2, C7.2, C8.2, C9.2, C10.2, C10_SUPERCAP.1, CHANGE_BUTTON.1, CHANGE_BUTTON.2, C_DELAY.2, D1.2 (GND), D3.1 (K), D6.2, D8.2, D9.2, D10.2, D11.2, D12.2, EPD_C1.2, EPD_C2.2, EPD_C5.2, EPD_C6.2, EPD_C7.2, EPD_C8.2, EPD_C9.2, EPD_C10.2, EPD_C11.2, EPD_C12.2, IC1.3 (GND), IC4.2 (VSS), J1.8, J1.17, J1.MP1, J1.MP2, J2.A1, J2.A12, J2.B1, J2.B12, J2.MP1, J2.MP2, J2.MP3, J2.MP4, J3.1, J4.G1 (GND_1), J4.G2 (GND_2), J4.G3 (GND_3), J4.G4 (GND_4), J4.P6 (VSS), MCP73831.2 (VSS), R1_PWRUSB.1, R2.1, R2-USB.2, R2-USB1.1, R2_BAT.1, R4.2, RESET_BUTTON.1, RESET_BUTTON.2, SENSOR2.1 (GND), SENSOR2.5 (SDO), SENSOR2.7 (GND), SJ1.1, TP4.TP, TP5.TP, U1.4 (GND), U1.9 (EXP), U2.1 (GND), U2.28 (GND), U2.29_1 (GND), U2.29_2 (GND), U2.29_3 (GND), U2.29_4 (GND), U2.29_5 (GND), U2.29_6 (GND), U2.29_7 (GND), U2.29_8 (GND), U2.29_9 (GND), U3.13 (GND), U4.1 (CTG), U4.4 (GND), U4.6 (QSTRT), U4.9 (EP)
GPIO8: R1.2, U2.10 (IO8)
I2C_PW: C1.1, C2.1, R1_PINH.2, R2-PINH.2, SENSOR2.2 (CSB), SENSOR2.6 (VDDIO), SENSOR2.8 (VDD), U2.17 (IO19)
INT_RTC: R1_PINH1.1, TP15.TP, U2.8 (IO0), U3.3 (SQW/!INT)
IO/BOOT: BOOT_BUTTON.3, BOOT_BUTTON.4, C6.1, R_BOOT.2, U2.15 (IO9)
IO/CHANGE: C10.1, CHANGE_BUTTON.3, CHANGE_BUTTON.4, R_CHANGE.2, U2.23 (IO15)
MISO: D12.1, J4.P7 (DAT0), R8.1, TP6.TP, U1.2 (DO(IO1)), U2.27 (IO2)
MOSI: D11.1, J1.14, J4.P3 (CMD), R7.1, TP7.TP, U1.5 (DI(IO0)), U2.7 (IO7)
unnamed: J2.A5, R2-USB1.2
unnamed: J2.B5, R2-USB.1
unnamed: C1_BAT1.1, D2.1 (CATHODE), IC4.1 (VIN), IC4.3 (CE), Q1.2 (S)
unnamed: C4.1, D3.2 (A), D4.1 (K)
unnamed: MCP73831.1 (STAT), R1_BAT.1
unnamed: CHG_LED.C, R1_BAT.2
unnamed: MCP73831.5 (PROG), R2_BAT.2
unnamed: EPD_C12.1, J1.24
unnamed: D7.1 (CATHODE), R_CAPACITOR.2
unnamed: EPD_C10.1, J1.22
unnamed: C_DELAY.1, IC1.5 (CT)
unnamed: EPD_C8.1, J1.20
unnamed: EPD_C7.1, J1.19
unnamed: EPD_C6.1, J1.18
unnamed: EPD_C2.1, J1.5
unnamed: EPD_C1.1, J1.4
PREVGH: D5.1 (K), EPD_C9.1, J1.21
PREVGL: D4.2 (A), EPD_C11.1, J1.23
RESE: J1.3, Q3.2 (S), R3.1
RESE': R2.2, R3.2, SJ1.2
RESET: C5.1, IC1.1 (VOUT), RESET_BUTTON.3, RESET_BUTTON.4, R_RESET.2, U2.3 (EN)
RTC_RST: U2.16 (IO18), U3.4 (!RST)
RX: TP2.TP, U2.24 (RXD0/GPIO17)
SCK: D10.1, J1.13, J4.P5 (CLK), R6.1, TP8.TP, U1.6 (CLK), U2.6 (IO6)
SCL: J3.4, R2-PINH.1, SENSOR2.4 (SCK), U2.20 (IO22), U3.16 (SCL), U4.7 (SCL)
SDA: J3.3, R1_PINH.1, SENSOR2.3 (SDI), U2.19 (IO21), U3.15 (SDA), U4.8 (SDA)
SRC: C4.2, D5.2 (A), L1.1, Q3.3 (D)
SS_SD: D8.1, J4.P2 (CD/DAT3), R10.1, U2.4 (IO4)
TX: TP1.TP, U2.25 (TXD0/GPIO16)
USB_D+: D1.1 (I/O1_1), U2.14 (IO13)
USB_D-: D1.3 (I/O2_1), U2.13 (IO12)
VBAT: C2_BAT.1, MCP73831.3 (VBAT), Q1.3 (D), TP3.TP, U4.2 (CELL), U4.3 (VDD)
VBUS: C1_BAT.1, C4_USB.1, C5_USB.1, CHG_LED.A, D1.5 (VBUS), D2.2 (ANODE), MCP73831.4 (VIN), PFMF.050.1.2, Q1.1 (G), R1_PWRUSB.2, TP14.TP
VRTC: C8.1, C10_SUPERCAP.2, R_CAPACITOR.1, U3.14 (VBAT)
VUSB: J2.A4, J2.A9, J2.B4, J2.B9, PFMF.050.1.1

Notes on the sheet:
USB C connector & ESD protection
LDO Voltage Regulator
SD Card
Display Type Selector
E-Paper Drive Circuit
Li-Po Battery Charging Controller
ESP32 C6
E-Paper Display Header
EPD Power
Environmental Sensor BME688
Voltage Supervisor + Reset & Boot / IO Button
Battery Charge Level
RTC Module DS3231SN
Test Pads
Qwiic / Stemma QT
SPI ESD Protection Lines
External NOR Flash 64MB
Tudor Zaharia
DMG2305UX-7
SD0805S020S1R0

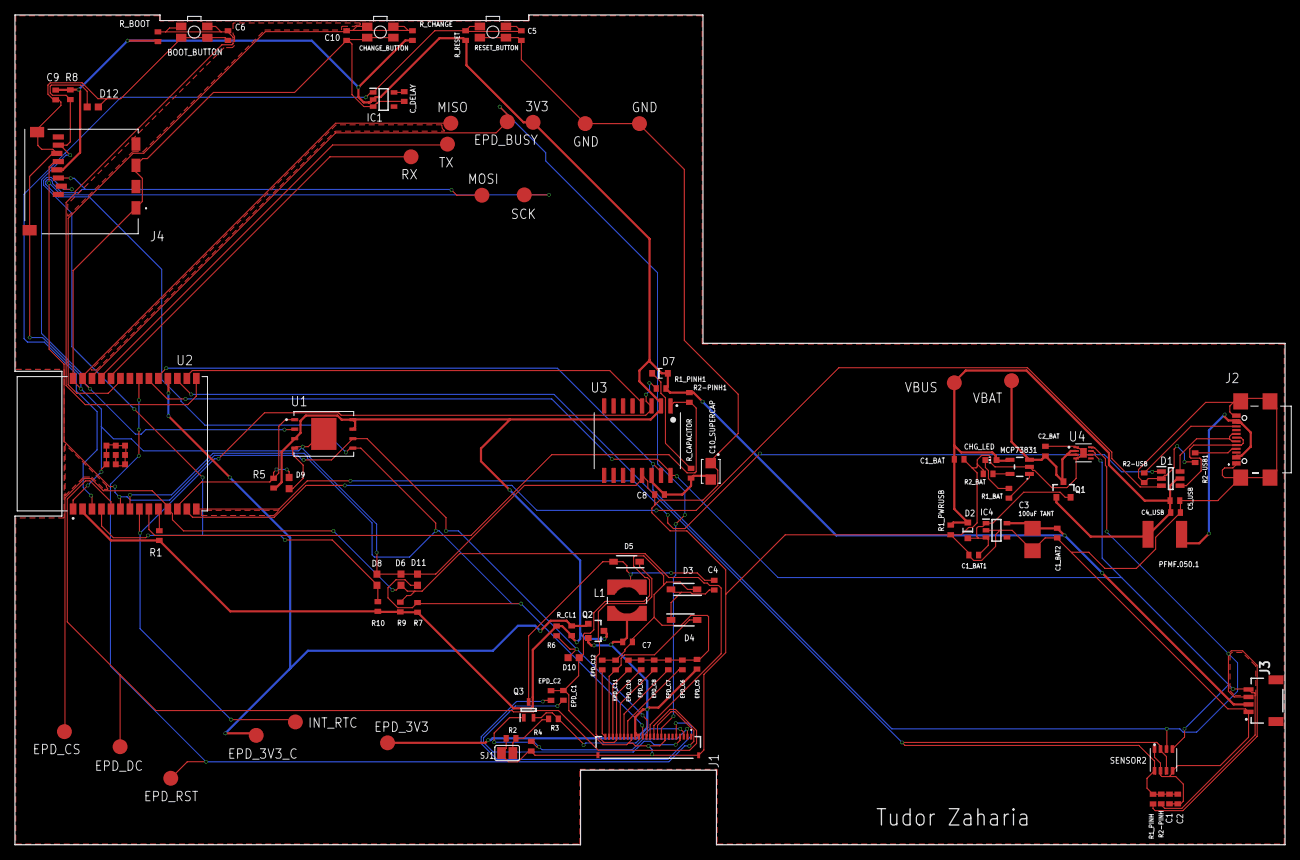
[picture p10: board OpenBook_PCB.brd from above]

Board: 2 copper layers, 170.2 x 111.2 mm, 103 parts (0 on the bottom side), 55 nets.

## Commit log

2025-03-23 Added design files.
    [OpenBook Enclosure_device_fusion.f3z, OpenBook_PCB.brd, OpenBook_schematic.sch]
2025-03-23 Corrected name of the file.
    [OpenBook_device_fusion.f3z]
2025-03-30 Updated design files.
    [OpenBook_PCB.brd, OpenBook_device_fusion.f3z, OpenBook_schematic.sch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]
2025-04-11 Solved all issues. Final product.
    [OpenBook_PCB.brd, OpenBook_device_fusion.f3z, OpenBook_schematic.sch]

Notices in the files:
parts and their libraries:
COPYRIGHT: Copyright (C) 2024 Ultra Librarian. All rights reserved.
